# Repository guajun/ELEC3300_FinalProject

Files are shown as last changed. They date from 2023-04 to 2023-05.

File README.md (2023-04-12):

# ELEC3300_FinalProject

CAN - 电机

SDIO - sd卡

I2S - 扬声器

CRC 电机驱动信息校验

spi - oled ST7735

adc - 功率

uart - ws2812

uart - 3DConn 

usb hid - 键盘

uart - rs485（硬件流控）

Timer - encoder interface 增量编码器

Timer - PWM 呼吸灯

I2C - 距离传感器 VL53L0X

GPIO - Valve

GPIO - Relay

# ZYD

## 难
spi - oled ST7735

uart - 3DConn

## 一般
uart - ws2812

## 简单
Timer - encoder interface 增量编码器

## 超简单
Timer - PWM 呼吸灯

adc - 功率

GPIO - Valve

GPIO - Relay

# LGY
CAN - 电机

SDIO - sd卡

I2S - 扬声器

CRC 电机驱动信息校验

usb hid - 键盘

uart - rs485（硬件流控）

I2C - 距离传感器 VL53L0X

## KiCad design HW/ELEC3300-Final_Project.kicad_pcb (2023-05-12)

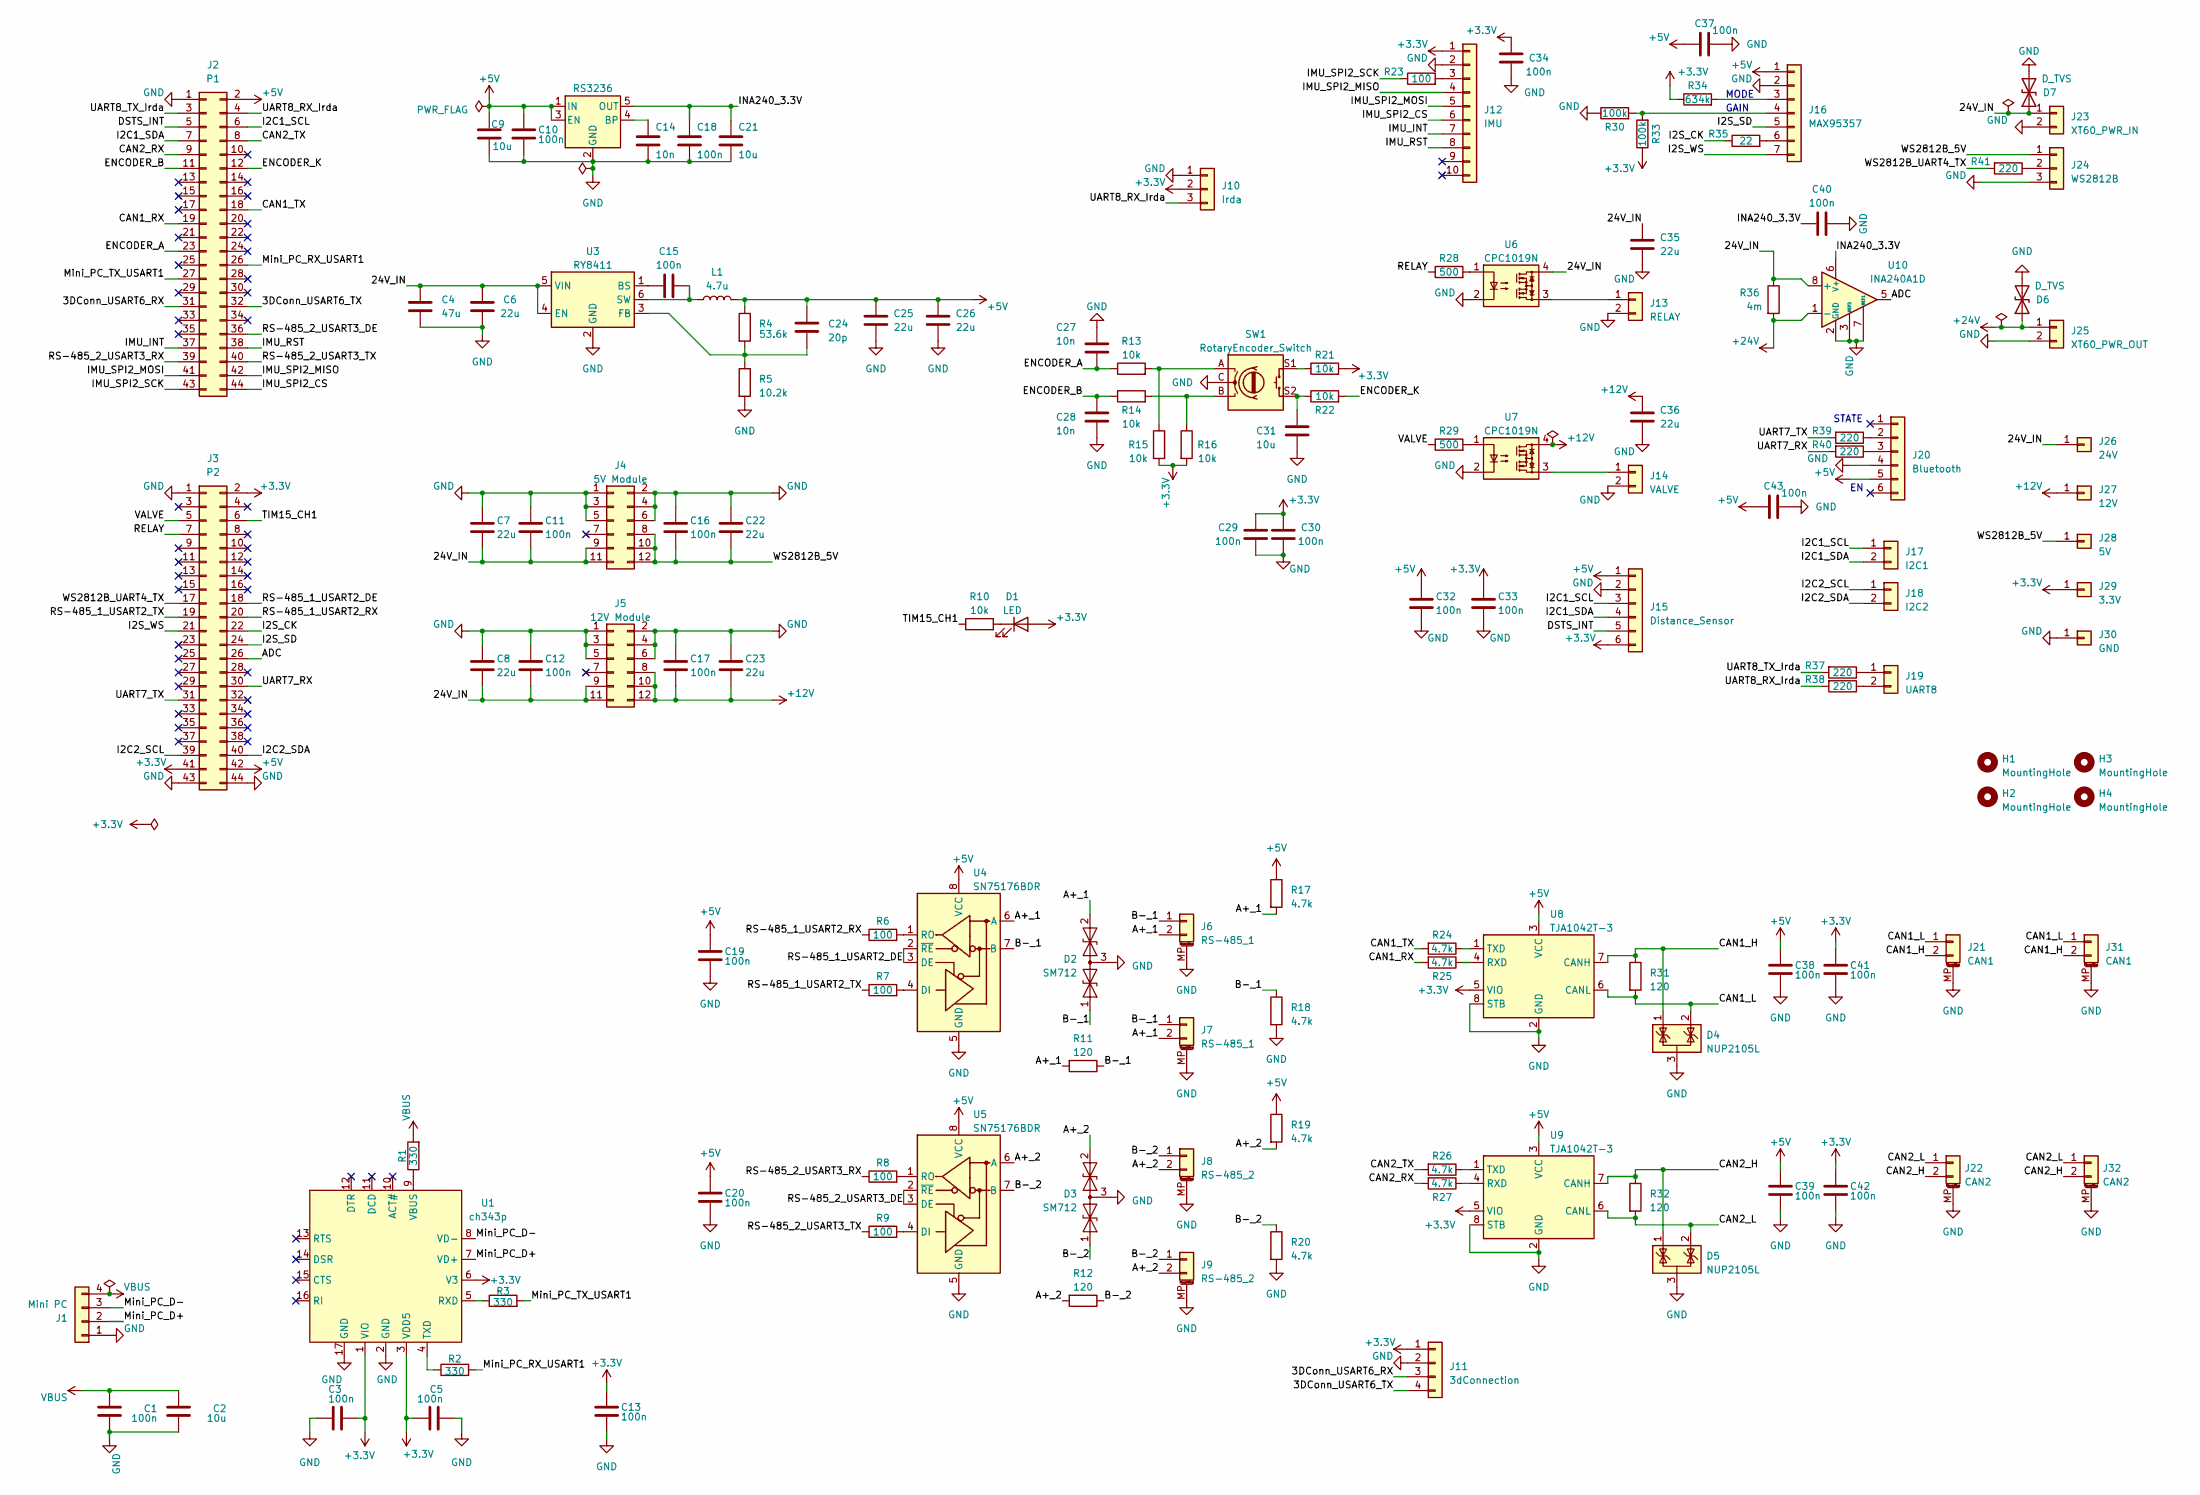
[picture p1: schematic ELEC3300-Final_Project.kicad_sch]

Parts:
C1, C3, C5, C10, C11, C12, C13, C15, C16, C17, C18, C19, C20, C29, C30, C32, C33, C34, C37, C38, C39, C40, C41, C42, C43: 100n; C_0603_1608Metric
C2, C9, C21: 10u; C_0805_2012Metric
C4: 47u; C_1206_3216Metric
C6, C7, C8, C22, C23, C25, C26, C35, C36: 22u; C_0805_2012Metric
C14, C27, C28: 10n; C_0603_1608Metric
C24: 20p; C_0603_1608Metric
C31: 10u; C_0603_1608Metric
D1: LED; LED_0603_1608Metric
D2, D3: SM712; SOT-23
D4, D5: NUP2105L; SOT-23
D6, D7: D_TVS; D_SMC
H1, H2, H3, H4: MountingHole; MountingHole_3.2mm_M3_ISO7380_Pad
J1: Mini PC; JST_PH_S4B-PH-K_1x04_P2.00mm_Horizontal
J2: P1; PinSocket_2x22_P2.54mm_Vertical
J3: P2; PinSocket_2x22_P2.54mm_Vertical
J4: 5V Module; 24V Buck
J5: 12V Module; 24V Buck
J6, J7: RS-485_1; JST_GH_SM02B-GHS-TB_1x02-1MP_P1.25mm_Horizontal
J8, J9: RS-485_2; JST_GH_SM02B-GHS-TB_1x02-1MP_P1.25mm_Horizontal
J10: Irda; PinSocket_1x03_P2.54mm_Vertical
J11: 3dConnection; PinHeader_1x04_P2.54mm_Horizontal
J12: IMU; PinSocket_1x10_P2.54mm_Vertical
J13: RELAY; JST_PH_S2B-PH-SM4-TB_1x02-1MP_P2.00mm_Horizontal
J14: VALVE; JST_PH_S2B-PH-SM4-TB_1x02-1MP_P2.00mm_Horizontal
J15: Distance_Sensor; PinSocket_1x06_P2.54mm_Horizontal
J16: MAX95357; PinSocket_1x07_P2.54mm_Vertical
J17: I2C1; PinHeader_1x02_P2.54mm_Vertical
J18: I2C2; PinHeader_1x02_P2.54mm_Vertical
J19: UART8; PinHeader_1x02_P2.54mm_Vertical
J20: Bluetooth; PinSocket_1x06_P2.54mm_Vertical
J21, J31: CAN1; JST_GH_SM02B-GHS-TB_1x02-1MP_P1.25mm_Horizontal
J22, J32: CAN2; JST_GH_SM02B-GHS-TB_1x02-1MP_P1.25mm_Horizontal
J23: XT60_PWR_IN; AMASS_XT60-M_1x02_P7.20mm_Vertical
J24: WS2812B; PinHeader_1x03_P2.54mm_Vertical
J25: XT60_PWR_OUT; AMASS_XT60-F_1x02_P7.20mm_Vertical
J26: 24V; TestPoint_Pad_4.0x4.0mm
J27: 12V; TestPoint_Pad_2.0x2.0mm
J28: 5V; TestPoint_Pad_2.0x2.0mm
J29: 3.3V; TestPoint_Pad_2.0x2.0mm
J30: GND; TestPoint_Pad_4.0x4.0mm
L1: 4.7u; L_Abracon_ASPI-0630LR
R1, R2, R3: 330; R_0603_1608Metric
R4: 53.6k; R_0603_1608Metric
R5: 10.2k; R_0603_1608Metric
R6, R7, R8, R9, R23: 100; R_0603_1608Metric
R10, R13, R14, R15, R16, R21, R22: 10k; R_0603_1608Metric
R11, R12, R31, R32: 120; R_0603_1608Metric
R17, R18, R19, R20, R24, R25, R26, R27: 4.7k; R_0603_1608Metric
R28, R29: 500; R_0603_1608Metric
R30, R33: 100k; R_0603_1608Metric
R34: 634k; R_0603_1608Metric
R35: 22; R_0603_1608Metric
R36: 4m; R_2512_6332Metric
R37, R38, R39, R40, R41: 220; R_0603_1608Metric
SW1: RotaryEncoder_Switch; RotaryEncoder_Alps_EC11E-Switch_Vertical_H20mm
U1: ch343p; CH343P
U2: RS3236; SOT-23-5
U3: RY8411; SOT-23-6
U4, U5: SN75176BDR; SOIC-8_3.9x4.9mm_P1.27mm
U6, U7: CPC1019N; SOP-4_3.8x4.1mm_P2.54mm
U8, U9: TJA1042T-3; SOIC-8_3.9x4.9mm_P1.27mm
U10: INA240A1D; SOIC-8_3.9x4.9mm_P1.27mm

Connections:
+3.3V: C3.1, C5.1, C13.1, C29.2, C30.2, C33.2, C34.2, C41.1, C42.1, D1.2 (A), J3.2, J3.41, J10.2, J11.1, J12.1, J15.6, J29.1, R15.2, R16.2, R21.2, R33.1, R34.1, U1.1 (VIO), U1.3 (VDD5), U1.6 (V3), U8.5 (VIO), U9.5 (VIO)
+5V: C9.1, C10.1, C19.1, C20.1, C24.1, C25.1, C26.1, C32.1, C37.1, C38.1, C39.1, C43.1, J2.2, J3.42, J15.1, J16.1, J20.5, L1.2, R4.1, R17.1, R19.1, U2.1 (IN), U2.3 (EN), U4.8 (VCC), U5.8 (VCC), U8.3 (VCC), U9.3 (VCC)
+12V: C17.2, C23.2, C36.1, J5.8, J5.10, J5.12, J27.1, U7.4
+24V: D6.1 (A1), J25.1, R36.2, U10.1 (-)
/3DConn_USART6_RX: J2.31, J11.3
/3DConn_USART6_TX: J2.32, J11.4
/24V_IN: C4.1, C6.1, C7.2, C8.2, C11.2, C12.2, C35.1, D7.1 (A1), J4.9, J4.11, J5.9, J5.11, J23.1, J26.1, R36.1, U3.4 (EN), U3.5 (VIN), U6.4, U10.8 (+)
/A+_1: D2.2 (A2), J6.2, J7.2, R11.2, R17.2, U4.6 (A)
/A+_2: D3.2 (A2), J8.2, J9.2, R12.2, R19.2, U5.6 (A)
/ADC: J3.26, U10.5
/B-_1: D2.1 (A1), J6.1, J7.1, R11.1, R18.1, U4.7 (B)
/B-_2: D3.1 (A1), J8.1, J9.1, R12.1, R20.1, U5.7 (B)
/CAN1_H: D4.1 (K), J21.2, J31.2, R31.1, U8.7 (CANH)
/CAN1_L: D4.2 (K), J21.1, J31.1, R31.2, U8.6 (CANL)
/CAN1_RX: J2.19, R25.2
/CAN1_TX: J2.18, R24.2
/CAN2_H: D5.1 (K), J22.2, J32.2, R32.1, U9.7 (CANH)
/CAN2_L: D5.2 (K), J22.1, J32.1, R32.2, U9.6 (CANL)
/CAN2_RX: J2.9, R27.2
/CAN2_TX: J2.8, R26.2
/DSTS_INT: J2.5, J15.5
/ENCODER_A: C27.2, J2.23, R13.1
/ENCODER_B: C28.1, J2.11, R14.1
/ENCODER_K: J2.12, R22.2
/I2C1_SCL: J2.6, J15.3, J17.1
/I2C1_SDA: J2.7, J15.4, J17.2
/I2C2_SCL: J3.39, J18.1
/I2C2_SDA: J3.40, J18.2
/I2S_CK: J3.22, R35.1
/I2S_SD: J3.24, J16.5
/I2S_WS: J3.21, J16.7
/IMU_INT: J2.37, J12.7
/IMU_RST: J2.38, J12.8
/IMU_SPI2_CS: J2.44, J12.6
/IMU_SPI2_MISO: J2.42, J12.4
/IMU_SPI2_MOSI: J2.41, J12.5
/IMU_SPI2_SCK: J2.43, R23.1
/INA240_3.3V: C18.1, C21.1, C40.1, U2.5 (OUT), U10.6 (V+)
/Mini_PC_D+: J1.2, U1.7 (VD+)
/Mini_PC_D-: J1.3, U1.8 (VD-)
/Mini_PC_RX_USART1: J2.26, R2.2
/Mini_PC_TX_USART1: J2.27, R3.2
/RELAY: J3.7, R28.1
/RS-485_1_USART2_DE: J3.18, U4.2 (~RE), U4.3 (DE)
/RS-485_1_USART2_RX: J3.20, R6.1
/RS-485_1_USART2_TX: J3.19, R7.1
/RS-485_2_USART3_DE: J2.36, U5.2 (~RE), U5.3 (DE)
/RS-485_2_USART3_RX: J2.39, R8.1
/RS-485_2_USART3_TX: J2.40, R9.1
/TIM15_CH1: J3.6, R10.1
/UART7_RX: J3.30, R40.2
/UART7_TX: J3.31, R39.2
/UART8_RX_Irda: J2.4, J10.3, R38.2
/UART8_TX_Irda: J2.3, R37.2
/VALVE: J3.5, R29.1
/WS2812B_5V: C16.2, C22.2, J4.8, J4.10, J4.12, J24.1, J28.1
/WS2812B_UART4_TX: J3.17, R41.2
GND: C1.2, C2.2, C3.2, C4.2, C5.2, C6.2, C7.1, C8.1, C9.2, C10.2, C11.1, C12.1, C13.2, C14.2, C16.1, C17.1, C18.2, C19.2, C20.2, C21.2, C22.1, C23.1, C25.2, C26.2, C27.1, C28.2, C29.1, C30.1, C31.2, C32.2, C33.1, C34.1, C35.2, C36.2, C37.2, C38.2, C39.2, C40.2, C41.2, C42.2, C43.2, D2.3 (common), D3.3 (common), D4.3 (A), D5.3 (A), D6.2 (A2), D7.2 (A2), J1.1, J2.1, J3.1, J3.43, J3.44, J4.1, J4.2, J4.3, J4.4, J4.5, J4.6, J5.1, J5.2, J5.3, J5.4, J5.5, J5.6, J6.MP (MountPin), J7.MP (MountPin), J8.MP (MountPin), J9.MP (MountPin), J10.1, J11.2, J12.2, J13.2, J14.2, J15.2, J16.2, J20.4, J21.MP (MountPin), J22.MP (MountPin), J23.2, J24.3, J25.2, J30.1, J31.MP (MountPin), J32.MP (MountPin), R5.2, R18.2, R20.2, R30.1, SW1.C, U1.2 (GND), U1.17 (GND), U2.2 (GND), U3.2 (GND), U4.5 (GND), U5.5 (GND), U6.2, U7.2, U8.2 (GND), U8.8 (STB), U9.2 (GND), U9.8 (STB), U10.2 (GND), U10.3 (REF2), U10.4 (GND), U10.7 (REF1)
unnamed: C31.1, R22.1, SW1.S2
unnamed: D1.1 (K), R10.2
unnamed: J12.3, R23.2
unnamed: J13.1, U6.3
unnamed: J14.1, U7.3
unnamed: J16.3, R34.2
unnamed: J16.4, R30.2, R33.2
unnamed: J16.6, R35.2
unnamed: J19.1, R37.1
unnamed: J19.2, R38.1
unnamed: J20.2, R39.1
unnamed: J20.3, R40.1
unnamed: J24.2, R41.1
unnamed: R13.2, R15.1, SW1.A
unnamed: R14.2, R16.1, SW1.B
unnamed: R21.1, SW1.S1
unnamed: R28.2, U6.1
unnamed: R29.2, U7.1
unnamed: R3.1, U1.5 (RXD)
unnamed: R2.1, U1.4 (TXD)
unnamed: R1.1, U1.9 (VBUS)
unnamed: C14.1, U2.4 (BP)
unnamed: C15.1, U3.1 (BS)
unnamed: C24.2, R4.2, R5.1, U3.3 (FB)
unnamed: C15.2, L1.1, U3.6 (SW)
unnamed: R7.2, U4.4 (DI)
unnamed: R6.2, U4.1 (RO)
unnamed: R9.2, U5.4 (DI)
unnamed: R8.2, U5.1 (RO)
unnamed: R25.1, U8.4 (RXD)
unnamed: R24.1, U8.1 (TXD)
unnamed: R27.1, U9.4 (RXD)
unnamed: R26.1, U9.1 (TXD)
VBUS: C1.1, C2.1, J1.4, R1.2

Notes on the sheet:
STATE
MODE
GAIN

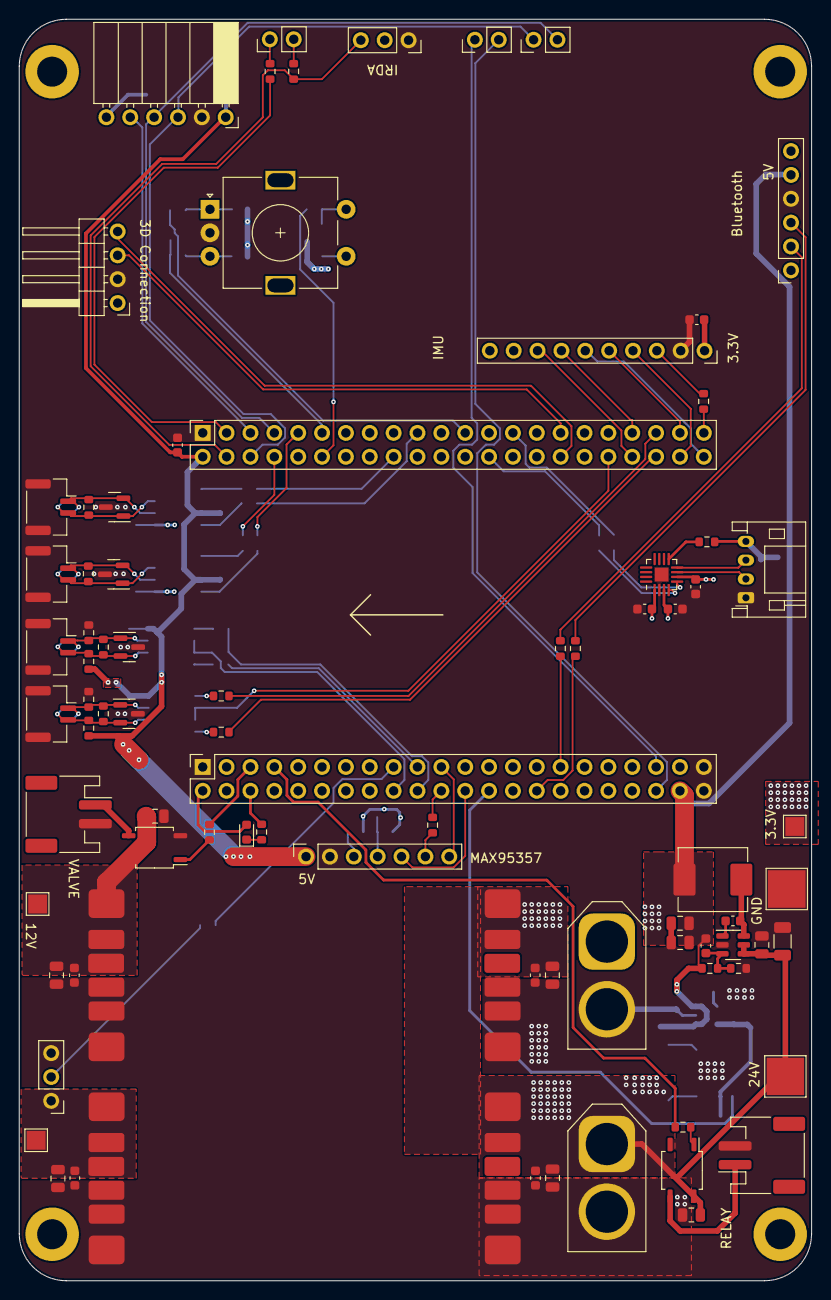
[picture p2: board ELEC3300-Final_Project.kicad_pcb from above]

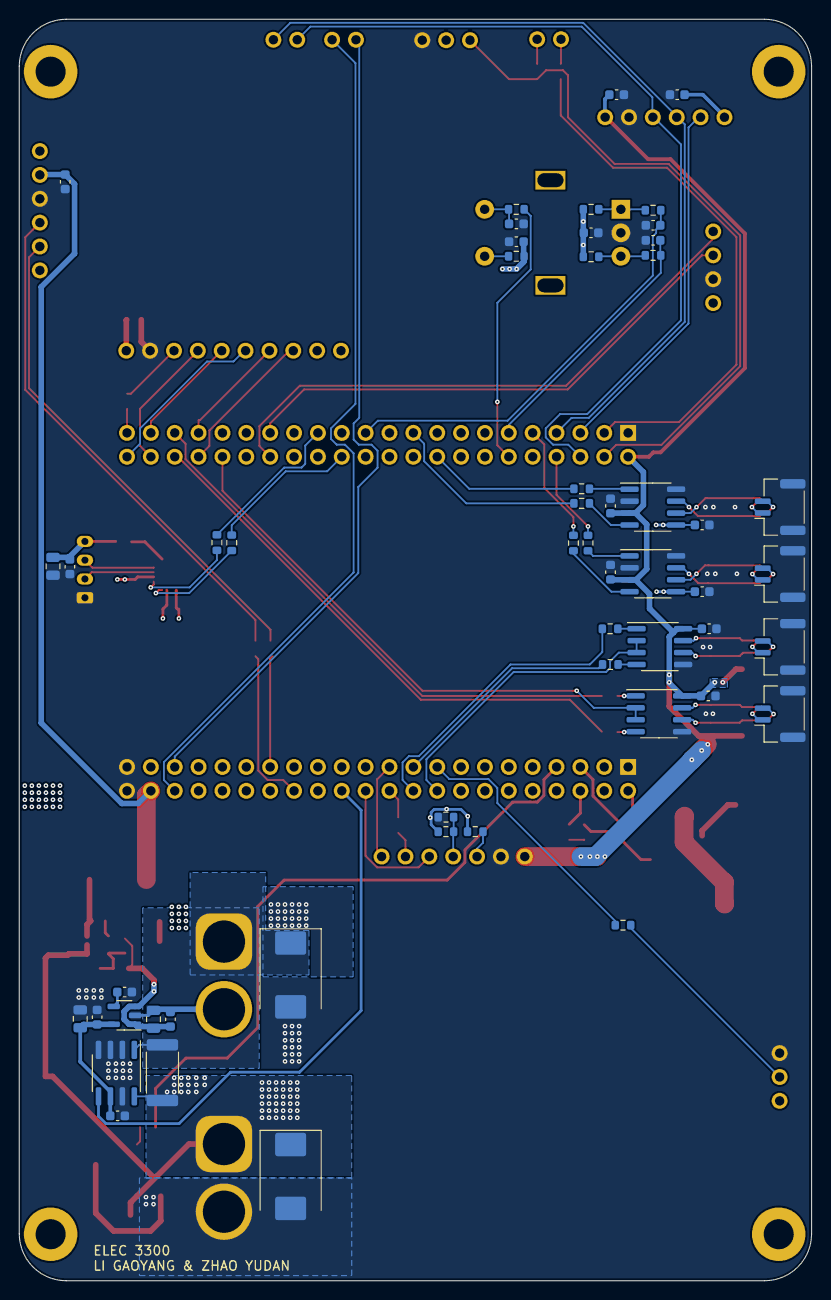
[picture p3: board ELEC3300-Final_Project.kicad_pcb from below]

Board: 4 copper layers, 84.3 x 134.3 mm, 139 parts (53 on the bottom side), 92 nets.

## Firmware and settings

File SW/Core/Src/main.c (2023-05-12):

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
/* Includes ------------------------------------------------------------------*/
#include "main.h"
#include "adc.h"
#include "crc.h"
#include "dma.h"
#include "fdcan.h"
#include "i2c.h"
#include "i2s.h"
#include "sdmmc.h"
#include "spi.h"
#include "tim.h"
#include "usart.h"
#include "usb_host.h"
#include "gpio.h"

/* USER CODE BEGIN Includes */
#include "RotaryEncoder.h"
#include "IMU.h"
#include "TemperatureSensor.h"
#include "SpaceMouse.h"
#include "BreathingLight.h"
#include "WS2812B.h"
#include "WAVPlayer.h"
#include "GO_M8010_6.h"
#include "DM4310.h"
#include "OS.h"
#include "LCD.h"
#include "string.h"
#include "HT4310.h"
#include "DM4310.h"
#include "Keyboard.h"
/* USER CODE END Includes */


/* USER CODE BEGIN PV */
uint32_t localTick = 0;
struct GRB grbArray[15];
/* USER CODE END PV */

void SystemClock_Config(void);
void PeriphCommonClock_Config(void);
void MX_USB_HOST_Process(void);

/**
  * @brief  The application entry point.
  * @retval int
  */
int main(void)
{
  /* Enable I-Cache---------------------------------------------------------*/
  SCB_EnableICache();

  /* MCU Configuration--------------------------------------------------------*/

  /* Reset of all peripherals, Initializes the Flash interface and the Systick. */
  HAL_Init();

  /* Configure the system clock */
  SystemClock_Config();

/* Configure the peripherals common clocks */
  PeriphCommonClock_Config();

  /* Initialize all configured peripherals */
  MX_GPIO_Init();
  MX_DMA_Init();
  MX_FDCAN1_Init();
  MX_FDCAN2_Init();
  MX_SDMMC1_SD_Init();
  MX_I2C1_Init();
  MX_I2S1_Init();
  MX_SPI2_Init();
  MX_USB_HOST_Init();
  MX_CRC_Init();
  MX_ADC1_Init();
  MX_I2C2_Init();
  MX_SPI4_Init();
  MX_TIM1_Init();
  MX_TIM2_Init();
  MX_TIM7_Init();
  MX_TIM15_Init();
  MX_USART3_UART_Init();
  MX_USART2_UART_Init();
  MX_USART1_UART_Init();
  MX_USART6_UART_Init();
  MX_UART7_Init();
  MX_UART4_Init();
  MX_UART8_IRDA_Init();
  MX_ADC3_Init();
  MX_TIM6_Init();
  /* USER CODE BEGIN 2 */
  HAL_Delay(500);
  RotaryEncoder_init();
  IMU_init();
  HAL_Delay(50);
  TemperatureSensor_init();
  SpaceMouse_init(); 
  HAL_Delay(10);
  BreathingLight_init();
  WAVPlayer_init();
  HAL_Delay(1000);
  DM4310_init();
  HT4310_init();
  LCD_init();

  GO_M8010_6_init();
  WAVPlayer_play();

  OS_init();
  /* USER CODE END 2 */

  /* Infinite loop */
  /* USER CODE BEGIN WHILE */
  while (1)
  {
    /* USER CODE END WHILE */
    MX_USB_HOST_Process();

    /* USER CODE BEGIN 3 */
    BreathingLight_update();
    uint32_t encoder = RotaryEncoder_read();

    char text[11] = "";
    memset(text, ' ', 10);
    sprintf(text, "%10u", encoder);
    LCD_ShowString(0, 14, ST7735Ctx.Width, 16, 12, text);

    char text2[11] = "";
    memset(text, 0, 10);
    switch (motorCtr)
    {
    case 0:
      
      sprintf(text2, "%10s", "Keyboard");
      LCD_ShowString(0, 28, ST7735Ctx.Width, 16, 12, text2);
      break;

    case 1:
      // char text2[11] = "";
      sprintf(text2, "%10s", "IMU");
      LCD_ShowString(0, 28, ST7735Ctx.Width, 16, 12, text2);
      break;

    case 2:
      // char text2[11] = "";
      sprintf(text2, "%10s", "SpaceMouse");
      LCD_ShowString(0, 28, ST7735Ctx.Width, 16, 12, text2);

      break;
    default:
      break;
    }

    char text3[6] = {0};
    sprintf(text3, "%5u", TemperatureSensor_getTemp());
    LCD_ShowString(0, 42, ST7735Ctx.Width, 16, 12, text3);

    if(localTick % 25)
    {
      uint16_t gx = (HAL_GetTick() >> 2) % 768;
      uint16_t rx = ((HAL_GetTick() >> 2) + 768 / 3) % 768;
      uint16_t bx = ((HAL_GetTick() >> 2) + 768 * 2 / 3) % 768;

      uint8_t g = gx < 256 ? gx : gx < 512 ? 255 : 768 - 1 - gx;
      uint8_t r = rx < 256 ? rx : rx < 512 ? 255 : 768 - 1 - rx;
      uint8_t b = bx < 256 ? bx : bx < 512 ? 255 : 768 - 1 - bx;


      uint32_t num = encoder >> 2;

      if((int)encoder < 0)
      {
        num = 0;
      }
      else if(num > 15)
      {
        num = 15;
      }

      for(uint8_t i = 0; i < 15; ++i)
      {
        if(i < num)
        {
          grbArray[i].g = g;
          grbArray[i].r = r;
          grbArray[i].b = b;
        }
        else
        {
          grbArray[i].g = 0;
          grbArray[i].r = 0;
          grbArray[i].b = 0;
        }
      }

      WS2812B_convert(grbArray, 15);
      WS2812B_send(15);
    }

    localTick++;
  }
  /* USER CODE END 3 */
}

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


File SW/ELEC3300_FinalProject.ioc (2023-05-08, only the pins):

Mcu.UserName=STM32H743VITx
PA0.Signal=UART4_TX
PA1.Signal=USART2_DE
PA10.Signal=USART1_RX
PA11.Signal=USB_OTG_FS_DM
PA12.Signal=USB_OTG_FS_DP
PA2.Signal=USART2_TX
PA3.Signal=USART2_RX
PA4.Signal=I2S1_WS
PA5.Signal=I2S1_CK
PA7.Signal=I2S1_SDO
PA9.Signal=USART1_TX
PB10.Signal=I2C2_SCL
PB11.Signal=I2C2_SDA
PB12.Signal=SPI2_NSS
PB13.Signal=SPI2_SCK
PB14.Signal=SPI2_MISO
PB15.Signal=SPI2_MOSI
PB5.Signal=FDCAN2_RX
PB6.Signal=FDCAN2_TX
PB7.Signal=GPXTI7
PB8.Signal=I2C1_SCL
PB9.Signal=I2C1_SDA
PC0.GPIO_Label=VBUS
PC0.Signal=GPIO_Output
PC10.Signal=SDMMC1_D2
PC11.Signal=SDMMC1_D3
PC12.Signal=SDMMC1_CK
PC13.GPIO_Label=K1
PC13.Signal=GPIO_Input
PC5.Signal=ADCx_INP8
PC6.Signal=USART6_TX
PC7.Signal=USART6_RX
PC8.Signal=SDMMC1_D0
PC9.Signal=SDMMC1_D1
PD0.Signal=FDCAN1_RX
PD1.Signal=FDCAN1_TX
PD10.GPIO_Label=IMU_RST
PD10.Signal=GPIO_Output
PD11.GPIO_Label=IMU_INT
PD11.Signal=GPXTI11
PD12.Signal=USART3_DE
PD2.Signal=SDMMC1_CMD
PD4.GPIO_Label=SD_DET
PD4.Signal=GPIO_Input
PD7.GPIO_Label=ENCODER_K
PD7.Signal=GPIO_Input
PD8.Signal=USART3_TX
PD9.Signal=USART3_RX
PE0.Signal=UART8_RX
PE1.Signal=UART8_TX
PE10.Signal=TIM1_CH2N
PE11.Signal=SPI4_NSS
PE12.Signal=SPI4_SCK
PE13.GPIO_Label=LCD_WR_RS
PE13.Signal=GPIO_Output
PE14.Signal=SPI4_MOSI
PE3.GPIO_Label=LED
PE3.Signal=GPIO_Output
PE4.GPIO_Label=VALVE
PE4.Signal=GPIO_Output
PE5.Signal=S_TIM15_CH1
PE6.GPIO_Label=RELAY
PE6.Signal=GPIO_Output
PE7.Signal=UART7_RX
PE8.Signal=UART7_TX

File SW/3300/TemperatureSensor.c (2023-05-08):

#include "TemperatureSensor.h"

#include "adc.h"
#include "stdint.h"

#define TEMPERATURE_SENSOR_VREF ((uint16_t)3320)

uint16_t adcData = 0;

void TemperatureSensor_callback(ADC_HandleTypeDef *hadc)
{
    adcData = HAL_ADC_GetValue(hadc);
};

void TemperatureSensor_init(void)
{
    HAL_ADCEx_Calibration_Start(&hadc3, ADC_CALIB_OFFSET, ADC_SINGLE_ENDED); // Calib
    HAL_ADC_RegisterCallback(&hadc3, HAL_ADC_CONVERSION_COMPLETE_CB_ID, TemperatureSensor_callback);
    HAL_ADC_Start_IT(&hadc3);
}

uint16_t TemperatureSensor_getTemp()
{
    return __HAL_ADC_CALC_TEMPERATURE(TEMPERATURE_SENSOR_VREF, adcData, ADC_RESOLUTION_12B);
}

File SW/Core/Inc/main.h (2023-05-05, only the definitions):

#define LED_Pin GPIO_PIN_3
#define LED_GPIO_Port GPIOE
#define VALVE_Pin GPIO_PIN_4
#define VALVE_GPIO_Port GPIOE
#define RELAY_Pin GPIO_PIN_6
#define RELAY_GPIO_Port GPIOE
#define K1_Pin GPIO_PIN_13
#define K1_GPIO_Port GPIOC
#define VBUS_Pin GPIO_PIN_0
#define VBUS_GPIO_Port GPIOC
#define LCD_WR_RS_Pin GPIO_PIN_13
#define LCD_WR_RS_GPIO_Port GPIOE
#define IMU_RST_Pin GPIO_PIN_10
#define IMU_RST_GPIO_Port GPIOD
#define IMU_INT_Pin GPIO_PIN_11
#define IMU_INT_GPIO_Port GPIOD
#define IMU_INT_EXTI_IRQn EXTI15_10_IRQn
#define SD_DET_Pin GPIO_PIN_4
#define SD_DET_GPIO_Port GPIOD
#define ENCODER_K_Pin GPIO_PIN_7
#define ENCODER_K_GPIO_Port GPIOD

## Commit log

2023-04-16 add dma
2023-04-18 config 3dConn uart
2023-04-18 creat module, modified timer config
2023-04-18 add IMU peripherals
2023-04-24 finish sdio write, fix bug of i2s
    [ELEC3300_FinalProject.ioc, main.c]
2023-04-25 finish. Remember to check voltage supply value
2023-04-25 finish convert, need to add DMA
2023-04-25 fix DMA
2023-04-26 finish config for 200Mhz DMA sdcard. update influenced clk
2023-04-27 finish DMA double buffer
2023-05-06 finish lcd, no DMA
2023-05-07 finish 2812 encoder
2023-05-08 finish encoder adjust speed
2023-05-08 finish IMU ctrl

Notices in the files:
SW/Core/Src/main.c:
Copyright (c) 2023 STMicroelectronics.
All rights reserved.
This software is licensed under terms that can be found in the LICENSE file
